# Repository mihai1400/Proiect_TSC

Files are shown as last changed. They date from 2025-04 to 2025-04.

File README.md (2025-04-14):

# Arhitectura Sistemului

## 1. Arhitectura Generală
Sistemul este construit în jurul **ESP32-C6-WROOM-1-N8** (microcontroler Wi-Fi 6 + Bluetooth 5 cu RISC-V) și include:

- **Alimentare & Baterie** (LDO, încărcător Li-Po, monitorizare nivel baterie)
- **Memorie** (Flash extern NOR 64MB, slot SD)
- **Senzori** (BME688 - temperatură/umiditate/presiune/VOC)
- **Afișaj** (E-Paper SPI)
- **Periferice** (RTC DS3231, butoane, LED-uri, USB-C)

## 2. Module & Interfețe cu ESP32-C6

### 2.1. Alimentare & Baterie
| Componentă | Interfață cu ESP32-C6 | Detalii |
|---|---|---|
| LDO (XC6220A331MR-G) | Nu (alimentare 3.3V) | Reglează 3.3V pentru întreg sistemul |
| Încărcător Baterie (MCP73831)  | GPIO4 (STAT) | Semnalizează starea încărcării (LED) |
| Monitor Baterie (MAX17048) | I2C (SDA: GPIO8, SCL: GPIO9)| Măsoară nivelul bateriei (%/tensiune) |

**Calcul consum:**
- ESP32-C6 (~80 mA în mod activ, ~5 µA în sleep)
- BME688 (~2.5 mA când active)
- E-Paper (~100 mA la refresh)
- **Total estimat:** ~200 mA (utilizare normală), sub 1 mA în sleep cu RTC activ

### 2.2. Memorie & Stocare
| Componentă | Interfață cu ESP32-C6 | Detalii |
|---|---|---|
| Flash NOR (W25Q512JVEIQ) | SPI0 (CS: GPIO12, CLK: GPIO14, MOSI: GPIO13, MISO: GPIO11) | Stochează firmware/date |
| Slot SD (J4) | SPI1 (CS: GPIO5, CLK: GPIO6, MOSI: GPIO7, MISO: GPIO10) | Stocare fișiere (FAT32) |

### 2.3. Senzori
| Componentă | Interfață cu ESP32-C6 | Detalii |
|---|---|---|
| BME688 | I2C (SDA: GPIO8, SCL: GPIO9)| Senzor ambiental (temperatură, umiditate, presiune, VOC) |
| RTC (DS3231SN) | I2C (SDA: GPIO8, SCL: GPIO9)| Ceas precis (±2 ppm) cu alarmă |

**Comunicație:**
- BME688 folosește I2C la 400 kHz (adresă `0x76`)
- DS3231 folosește I2C la 100 kHz (adresă `0x68`)

### 2.4. Afișaj E-Paper
| Componentă | Interfață cu ESP32-C6 | Detalii |
|---|---|---|
| Driver E-Paper  | SPI2 (CS: GPIO15, DC: GPIO16, RST: GPIO17, BUSY: GPIO18) | SPI dedicat pentru afișaj |

**Specificații:**
- Rezoluție: 800x600 (4.2" monocrom)
- Consum: ~100 mA la refresh, 0 mA în stare statică

### 2.5. Periferice & I/O
| Componentă | Interfață cu ESP32-C6 | Detalii |
|---|---|---|
| Buton BOOT | GPIO0 | Resetare în mod flash |
| Buton CHANGE | GPIO1 | Schimbă afișajul |
| LED-uri (D1-D12) | GPIO2, GPIO3 | Indicatori vizuali |
| USB-C (J1) | GPIO20 (D+), GPIO21 (D-) | Comunicație serială (CDC) |

## 3. Alocarea Pinilor ESP32-C6
| Pin ESP32-C6 | Funcție | Componentă |
|---|---|---|
| GPIO0 | BOOT | Buton BOOT |
| GPIO1 | INPUT | Buton CHANGE |
| GPIO2-3 | OUTPUT | LED-uri |
| GPIO4 | INPUT | MCP73831 (STAT) |
| GPIO5 | CS | Slot SD |
| GPIO6-7 | SCK/MOSI | Slot SD |
| GPIO8-9 | SDA/SCL | BME688 + DS3231 (I2C) |
| GPIO10 | MISO | Slot SD |
| GPIO11 | MISO | Flash NOR |
| GPIO12 | CS | Flash NOR |
| GPIO13-14 | MOSI/SCK | Flash NOR |
| GPIO15-18 | SPI EPD | Afișaj E-Paper |
| GPIO20-21 | USB D+/D- | USB-C |

## 4. Optimizare Consum Energie
- **Sleep Mode:** ESP32-C6 intră în Deep Sleep cu RTC activ (~5 µA), trezit de DS3231 (alarmă) sau butoane
- **E-Paper:** Folosește energie doar la refresh
- **Senzori:** BME688 este pornit periodic (e.g., la 1 minut)

## 5. Diagramă
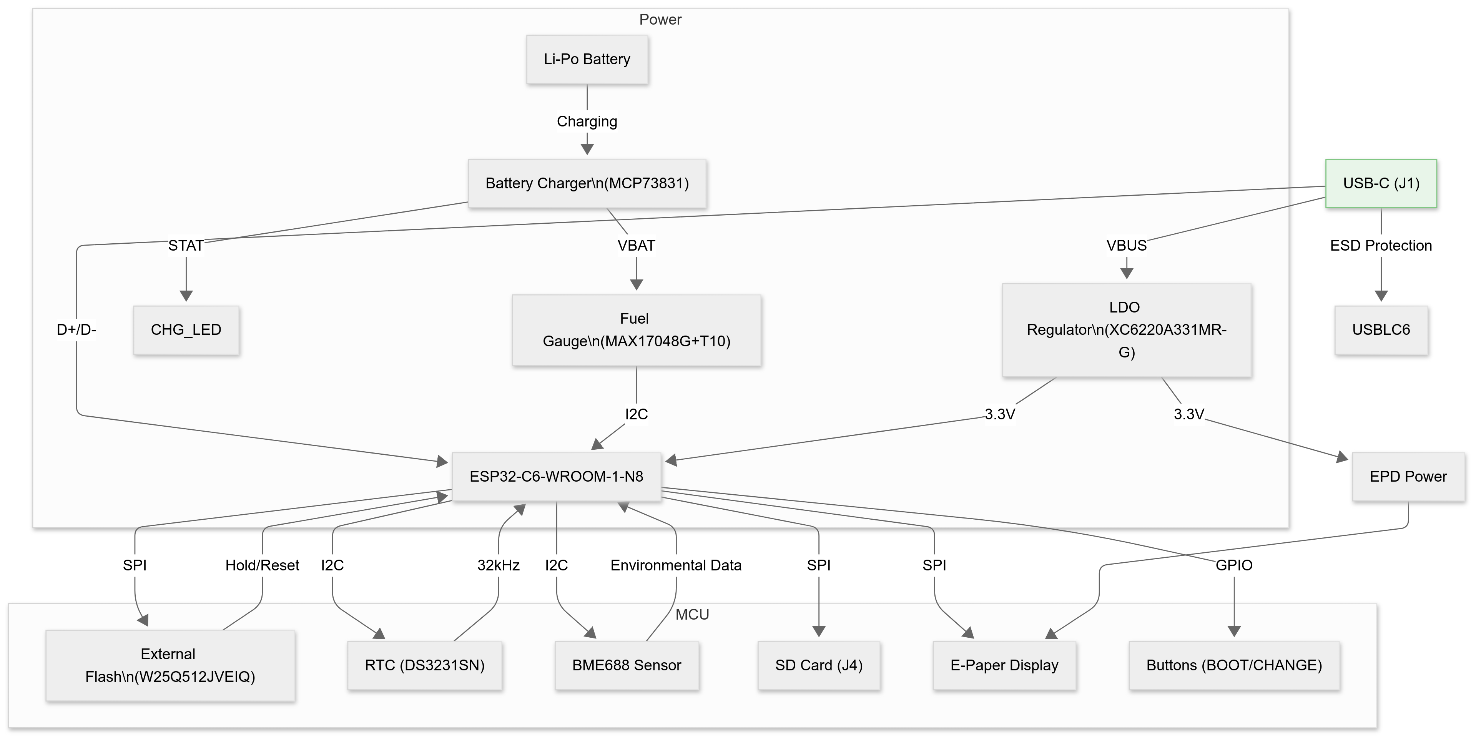
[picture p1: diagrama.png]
Architecture Diagram


## 6. BOM

| Device Module | Amount | Datasheet | Shop |
| --- | --- | ---| ---|
| 112A-TAAR-R03_ATTEND | 1 | https://www.attend.com.tw/en/product.php?act=view&id=253 | https://www.digikey.com/en/products/detail/attend-technology/112A-TAAR-R03/17633923 |
| BD5229G-TR | 1 | https://www.digikey.ph/en/products/detail/rohm-semiconductor/BD5229G-TR/658502 | https://www.digikey.ph/en/products/detail/rohm-semiconductor/BD5229G-TR/658502 |
| BUTTON_COSYOMV1 | 3 | https://components101.com/switches/push-button | https://uk.farnell.com/wurth-elektronik/430182043816/switch-160gf-6x6mm-smd-4-3mm-act/dp/2065105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 |
| CPH3225A | 1 | https://www.digikey.com/en/products/detail/seiko-instruments/CPH3225A/8692444 | https://www.digikey.com/en/products/detail/seiko-instruments/CPH3225A/8692444 |
| DS3231SN | 1 | https://www.digikey.com/en/products/detail/analog-devices-inc-maxim-integrated/DS3231SN/1197576 | https://www.digikey.com/en/products/detail/analog-devices-inc-maxim-integrated/DS3231SN/1197576 |
| BME680 | 1 | https://www.sparkfun.com/sparkfun-environmental-sensor-breakout-bme680-qwiic.html | https://www.sparkfun.com/sparkfun-environmental-sensor-breakout-bme680-qwiic.html |
| MCP73831 | 1 | https://www.microchip.com/en-us/product/mcp73831 | https://www.microchipdirect.com/product/MCP73831T-2ADI/OT |
| C6-WROOM-1-N8 | 1 | https://www.espressif.com/sites/default/files/documentation/esp32-c6-wroom-1_wroom-1u_datasheet_en.pdf | https://www.adafruit.com/product/5671 |
| FH34SRJ-24S-0.5SH_99_ | 1 | https://www.hirose.com/product/p/CL0580-1255-6-99 | https://www.hirose.com/product/p/CL0580-1255-6-99 |
| MAX17048G+T10 | 1 | https://eu.mouser.com/ProductDetail/Analog-Devices-Maxim-Integrated/MAX17048G+T10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 | https://eu.mouser.com/ProductDetail/Analog-Devices-Maxim-Integrated/MAX17048G+T10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 |
| MBR0530 | 3 | https://www.digikey.com/en/products/detail/onsemi/MBR0530/1048783 | https://www.digikey.com/en/products/detail/onsemi/MBR0530/1048783 |
| PGB1010603MR | 6 | https://www.digikey.com/en/products/detail/littelfuse-inc/PGB1010603MR/715755 | https://www.digikey.com/en/products/detail/littelfuse-inc/PGB1010603MR/715755 |
| SAMACSYS_PARTS_USB4110-GF-A | 1 | https://www.digikey.ro/en/products/detail/gct/USB4110-GF-A/10384547 | https://www.digikey.ro/en/products/detail/gct/USB4110-GF-A/10384547 |
| SI1308EDL-T1-GE3 | 1 | https://www.digikey.com/en/products/detail/vishay-siliconix/SI1308EDL-T1-GE3/4876435 | https://www.digikey.com/en/products/detail/vishay-siliconix/SI1308EDL-T1-GE3/4876435 |
| SJ | 1 | https://www.digikey.com/en/products/detail/cui-devices/SJ1-3514N/738685 | https://www.digikey.com/en/products/detail/cui-devices/SJ1-3514N/738685 |
| USBLC6-2SC6Y | 1 | https://www.digikey.com/en/products/detail/stmicroelectronics/USBLC6-2SC6Y/2819177 | https://www.digikey.com/en/products/detail/stmicroelectronics/USBLC6-2SC6Y/2819177 |
| W25Q512JVEIQ | 1 | https://www.digikey.com/en/products/detail/winbond-electronics/W25Q512JVEIQ/10244706 | https://www.digikey.com/en/products/detail/winbond-electronics/W25Q512JVEIQ/10244706 |
| XC6220A331MR-G | 1 | https://www.digikey.com/en/products/detail/torex-semiconductor-ltd/XC6220B331MR-G/2138177 | https://www.digikey.com/en/products/detail/torex-semiconductor-ltd/XC6220B331MR-G/2138177 |
| SD0805S020S1R0 | 2 | https://www.digikey.com/en/products/detail/kyocera-avx/SD0805S020S1R0/3749517 | https://www.digikey.com/en/products/detail/kyocera-avx/SD0805S020S1R0/3749517 |
| LTSPICE_C 100nF | 8 | https://www.digikey.com/en/products/detail/nextgen-components/0402B104K500HI/22601924 | https://www.digikey.com/en/products/detail/nextgen-components/0402B104K500HI/22601924 |
| LTSPICE_C 10nF | 1 | https://www.amazon.com/ALLECIN-Electrolytic-Capacitor-0-2x0-43in-Capacitors/dp/B0CMQC587X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 | https://www.amazon.com/ALLECIN-Electrolytic-Capacitor-0-2x0-43in-Capacitors/dp/B0CMQC587X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 |
| LTSPICE_C 4.7uF | 6 | https://www.amazon.com/ALLECIN-Electrolytic-Capacitor-0-2x0-43in-Capacitors/dp/B0CMQC587X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 | https://www.amazon.com/ALLECIN-Electrolytic-Capacitor-0-2x0-43in-Capacitors/dp/B0CMQC587X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 |
| LTSPICE_C 1uF | 10 | https://www.amazon.com/ALLECIN-Electrolytic-Capacitor-0-2x0-43in-Capacitors/dp/B0CMQC587X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 | https://www.amazon.com/ALLECIN-Electrolytic-Capacitor-0-2x0-43in-Capacitors/dp/B0CMQC587X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 |
| LTSPICE_C 0.1uF | 1 | https://www.digikey.com/en/products/detail/samsung-electro-mechanics/CL10E104KC8VPNC/20498486 | https://www.digikey.com/en/products/detail/samsung-electro-mechanics/CL10E104KC8VPNC/20498486 |
| ADAFRUIT_LED | 1 | https://www.adafruit.com/product/4684 | https://www.adafruit.com/product/4684 |
| ESP32_VARISTOR | 1 | https://uk.rs-online.com/web/p/varistors/9012743 | https://uk.rs-online.com/web/p/varistors/9012743 |
| CT3528 (RCL_CPOL-EU) 100uF | 1 | https://www.datasheetarchive.com/?q=ct3528 |  |
| DMG2305UX-7 20V/4.2A/52mO/1.4W | 2 | https://www.digikey.com/en/products/detail/diodes-incorporated/DMG2305UX-7/4340667 | https://www.digikey.com/en/products/detail/diodes-incorporated/DMG2305UX-7/4340667 |
| IND-4828-WE-TPC-WRE | 1 | https://www.axel-gl.com/en/asone/d/64-0172-48/ | https://www.axel-gl.com/en/asone/d/64-0172-48/ |
| JS-1MM(QWIIC_CONNECTOR) | 1 | https://www.sparkfun.com/qwiic-jst-connector-smd-4-pin-horizontal.html | https://www.sparkfun.com/qwiic-jst-connector-smd-4-pin-horizontal.html |
| LTSPICE_R 5k1 | 2 |  | https://www.amazon.com/BOJACK-Values-Resistor-Resistors-Assortment/dp/B08FD1XVL6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 |
| LTSPICE_R 100k | 1 |  | https://www.amazon.com/BOJACK-Values-Resistor-Resistors-Assortment/dp/B08FD1XVL6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 |
| LTSPICE_R 2.2 | 1 |  | https://www.amazon.com/BOJACK-Values-Resistor-Resistors-Assortment/dp/B08FD1XVL6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 |
| LTSPICE_R 10k | 16 |  | https://www.amazon.com/BOJACK-Values-Resistor-Resistors-Assortment/dp/B08FD1XVL6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 |
| LTSPICE_R 0.47 | 1 |  | https://www.amazon.com/BOJACK-Values-Resistor-Resistors-Assortment/dp/B08FD1XVL6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 |
| LTSPICE_R 2k | 1 |  | https://www.amazon.com/BOJACK-Values-Resistor-Resistors-Assortment/dp/B08FD1XVL6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 |
| LTSPICE_R 200 | 1 |  | https://www.amazon.com/BOJACK-Values-Resistor-Resistors-Assortment/dp/B08FD1XVL6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 |
| LTSPICE_R 15 | 1 |  | https://www.amazon.com/BOJACK-Values-Resistor-Resistors-Assortment/dp/B08FD1XVL6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 |
| Test Pad TP20R | 17 | https://us.misumi-ec.com/vona2/detail/221005496391/?HissuCode=TP20R-24 | https://us.misumi-ec.com/vona2/detail/221005496391/?HissuCode=TP20R-24 |

## 7. Concluzii
- ESP32-C6 este nucleul sistemului, cu 3 interfețe SPI (Flash, SD, E-Paper) și I2C partajat (BME688 + DS3231)
- BME688 oferă date ambientale, iar DS3231 menține timpul precis
- Consum redus în sleep (~5 µA) permite funcționare pe baterie >1 lună

Probleme : 
 - Nu pot genera fiserul .step (se blocheaza Fusion-ul cand incerc)

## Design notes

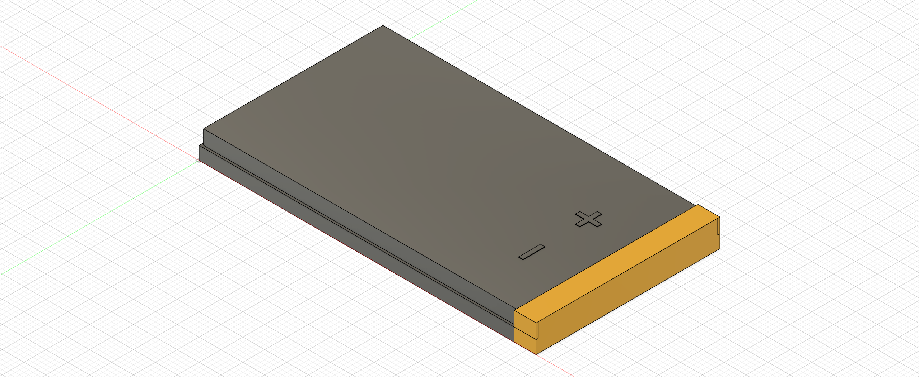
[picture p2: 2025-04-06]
Images/Baterie v1.png

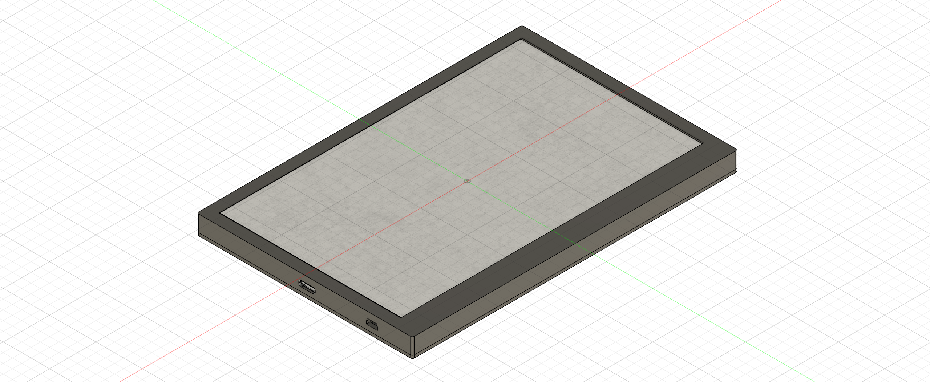
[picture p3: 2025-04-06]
Images/EBOOKREADER.png

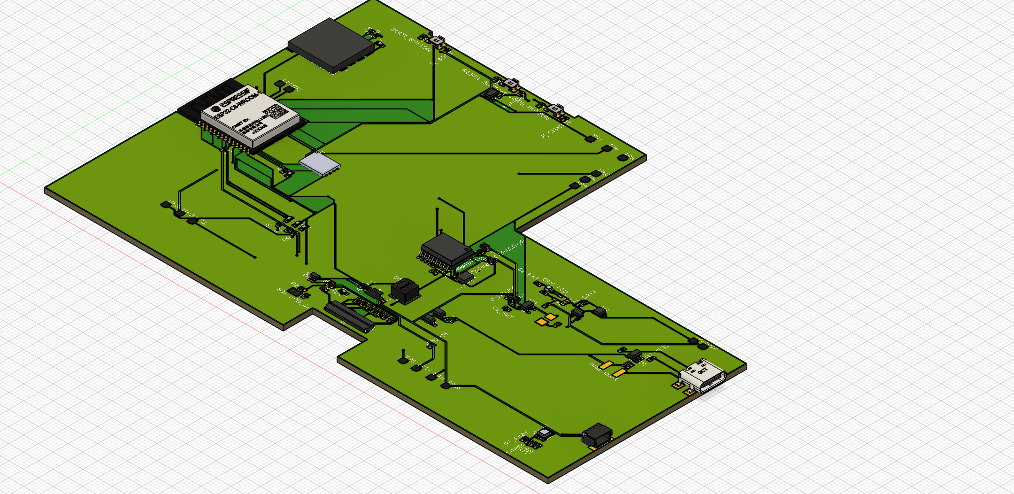
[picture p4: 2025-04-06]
Images/ProiectTSC v4.png

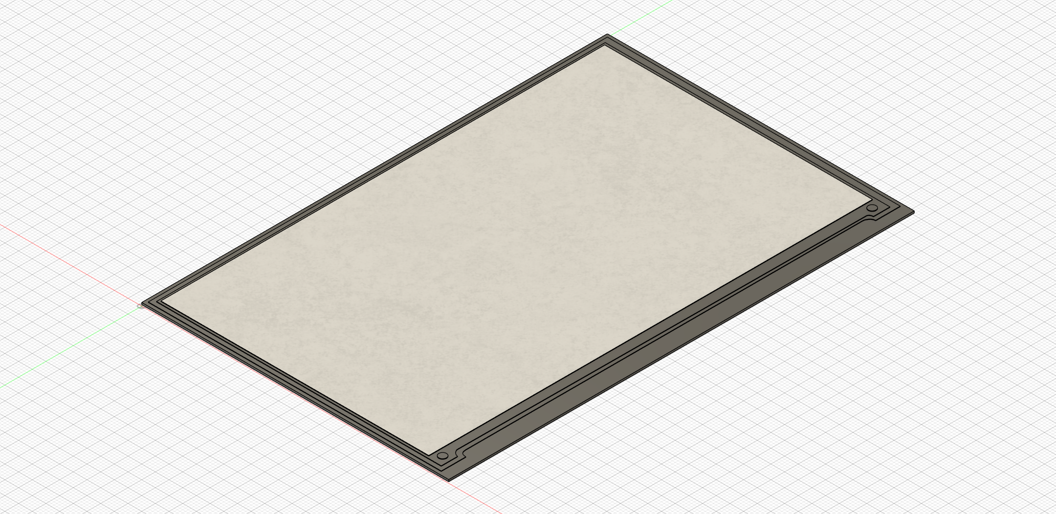
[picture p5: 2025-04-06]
Images/Display v4.png

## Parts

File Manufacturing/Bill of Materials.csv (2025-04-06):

BOOT_BUTTON | 36.65 | 112.67 | 180.00 | BUTTON_CUSYOMV1 | MYBUTTON
C1 | 170.35 | 11.74 | 90.00 | 100nf | ESP32_WROVER_EAGLE-LTSPICE_C0402
C10 | 72.51 | 112.21 | 270.00 | 100nF | ESP32_WROVER_EAGLE-LTSPICE_C0402
C10_SUPERCAP | 110.76 | 48.41 | 270.00 | CPH3225A | CAPCP3225X100N
C1_BAT | 126.31 | 46.88 | 0.00 | 4.7uF | ESP32_WROVER_EAGLE-LTSPICE_C0402
C1_BAT1 | 139.51 | 50.62 | 90.00 | 4.7uF | ESP32_WROVER_EAGLE-LTSPICE_C0402
C1_BAT2 | 137.87 | 61.45 | 90.00 | 4.7uF | ESP32_WROVER_EAGLE-LTSPICE_C0402
C2 | 171.77 | 11.84 | 90.00 | 100nf | ESP32_WROVER_EAGLE-LTSPICE_C0402
C2_BAT | 124.25 | 59.41 | 0.00 | 4.7uF | ESP32_WROVER_EAGLE-LTSPICE_C0402
C3 | 136.08 | 50.48 | 270.00 | 100uF TANT | RCL_CT3528
C4 | 120.74 | 34.42 | 90.00 | 4.7uF/25V | ESP32_WROVER_EAGLE-LTSPICE_C0402
C4_USB | 163.22 | 50.13 | 0.00 | 100nF | ESP32_WROVER_EAGLE-LTSPICE_C0402
C5 | 57.57 | 112.21 | 270.00 | 1uF | ESP32_WROVER_EAGLE-LTSPICE_C0402
C5_USB | 163.21 | 51.43 | 0.00 | 4.7uF | ESP32_WROVER_EAGLE-LTSPICE_C0402
C6 | 32.61 | 112.21 | 270.00 | 100nF | ESP32_WROVER_EAGLE-LTSPICE_C0402
C7 | 102.62 | 28.14 | 0.00 | 10uF | ESP32_WROVER_EAGLE-LTSPICE_C0402
C8 | 103.27 | 45.19 | 0.00 | 100nF | ESP32_WROVER_EAGLE-LTSPICE_C0402
C9 | 22.45 | 104.72 | 90.00 | 100nF | ESP32_WROVER_EAGLE-LTSPICE_C0402
CHANGE_BUTTON | 76.61 | 112.73 | 180.00 | BUTTON_CUSYOMV1 | MYBUTTON
C_DELAY | 123.20 | 50.60 | 90.00 | 100nF | ESP32_WROVER_EAGLE-LTSPICE_C0402
D1 | 162.18 | 54.30 | 0.00 | USBLC6-2SC6Y | SOT95P280X145-6N
D10 | 68.35 | 36.39 | 90.00 | PGB1010603MR | DIOC1608X36N
D11 | 27.59 | 102.84 | 0.00 | PGB1010603MR | DIOC1608X36N
D12 | 93.99 | 24.23 | 0.00 | PGB1010603MR | DIOC1608X36N
D2 | 125.60 | 50.52 | 90.00 | ESP32_WROVER_AVX---SD0805S020S1R0_AVX_SD0805S020S1R0_0_0AVX_SD0805S020S1R0_0_0 | ESP32_WROVER_AVX---SD0805S020S1R0_AVX_SD0805S020S1R0_0
D3 | 116.94 | 33.52 | 180.00 | MBR0530 | SOD3716X135N
D4 | 116.96 | 29.97 | 0.00 | MBR0530 | SOD3716X135N
D5 | 103.34 | 36.94 | 180.00 | MBR0530 | SOD3716X135N
D6 | 50.32 | 49.59 | 90.00 | PGB1010603MR | DIOC1608X36N
D7 | 104.87 | 60.98 | 0.00 | ESP32_WROVER_AVX---SD0805S020S1R0_AVX_SD0805S020S1R0_0_0AVX_SD0805S020S1R0_0_0 | ESP32_WROVER_AVX---SD0805S020S1R0_AVX_SD0805S020S1R0_0
D8 | 63.33 | 36.29 | 90.00 | PGB1010603MR | DIOC1608X36N
D9 | 66.14 | 36.39 | 90.00 | PGB1010603MR | DIOC1608X36N
EPC_C6 | 110.16 | 24.09 | 90.00 | 1uF/50V | ESP32_WROVER_EAGLE-LTSPICE_C0402
EPC_C8 | 106.34 | 24.09 | 90.00 | 1uF/50V | ESP32_WROVER_EAGLE-LTSPICE_C0402
EPD_C1 | 88.53 | 16.59 | 90.00 | 1uF/50V | ESP32_WROVER_EAGLE-LTSPICE_C0402
EPD_C10 | 102.52 | 24.09 | 90.00 | 1uF/50V | ESP32_WROVER_EAGLE-LTSPICE_C0402
EPD_C11 | 100.61 | 24.09 | 90.00 | 1uF/50V | ESP32_WROVER_EAGLE-LTSPICE_C0402
EPD_C12 | 98.70 | 24.09 | 90.00 | 1uF/50V | ESP32_WROVER_EAGLE-LTSPICE_C0402
EPD_C2 | 89.69 | 21.78 | 0.00 | 1uF/50V | ESP32_WROVER_EAGLE-LTSPICE_C0402
EPD_C5 | 124.54 | 23.39 | 90.00 | 0.1uF/50V | ESP32_WROVER_EAGLE-LTSPICE_C0402
EPD_C7 | 108.15 | 24.09 | 90.00 | 1uF/50V | ESP32_WROVER_EAGLE-LTSPICE_C0402
EPD_C9 | 104.53 | 24.09 | 90.00 | 1uF/50V | ESP32_WROVER_EAGLE-LTSPICE_C0402
GHC_LED | 127.92 | 59.53 | 90.00 |  | ADAFRUIT_CHIP-LED0603
IC1 | 129.58 | 50.48 | 0.00 | BD5229G-TR | SOT95P280X125-5N
IC4 | 61.69 | 106.50 | 0.00 | XC6220A331MR-G | SOT95P280X120-5N
J1 | 102.58 | 17.78 | 0.00 | FH34SRJ-24S-0.5SH_99_ | FH34SRJ24S05SH99
J2 | 179.27 | 58.60 | 90.00 | SAMACSYS_PARTS_USB4110-GF-A | SAMACSYS_PARTS_USB4110GFA
J3 | 179.74 | 23.56 | 90.00 | QWIIC_RIGHT_ANGLE | JST04_1MM_RA
J4 | 21.00 | 93.15 | 270.00 | 112A-TAAR-R03_ATTEND | 112ATAARR03ATTEND
L1 | 105.23 | 33.55 | 0.00 | 744043680IND_4828-WE-TPC_WRE | IND_4828-WE-TPC_WRE
MCP73831 | 132.99 | 58.63 | 90.00 | ESP32_WROVER_SPARKFUN-IC-POWER_MCP73831 | ESP32_WROVER_SPARKFUN-IC-POWER_SOT23-5
PFMF.050.1 | 161.86 | 47.20 | 180.00 | ESP32C6_VARISTORCN1812 | ESP32C6_VARISTOR_CT/CN1812
Q1 | 140.29 | 56.91 | 0.00 | 20V/4.2A/52mΩ/1.4W | ESP32_WROVER_SPARKFUN-DISCRETESEMI_SOT23-3
Q2 | 99.53 | 29.04 | 270.00 | 20V/4.2A/52mΩ/1.4W | ESP32_WROVER_SPARKFUN-DISCRETESEMI_SOT23-3
Q3 | 84.96 | 23.36 | 90.00 | SI1308EDL-T1-GE3 | SOT65P210X110-3N
R1 | 31.93 | 45.77 | 270.00 | 10K | ESP32_WROVER_EAGLE-LTSPICE_R0402
R10 | 24.40 | 104.69 | 90.00 | 10K | ESP32_WROVER_EAGLE-LTSPICE_R0402
R1_BAT | 127.93 | 57.90 | 0.00 | 200 | ESP32_WROVER_EAGLE-LTSPICE_R0402
R1_PINH | 167.34 | 11.74 | 90.00 | 10K | ESP32_WROVER_EAGLE-LTSPICE_R0402
R1_PINH1 | 107.99 | 48.29 | 90.00 | 10K | ESP32_WROVER_EAGLE-LTSPICE_R0402
R1_PWRUSB | 105.28 | 59.16 | 180.00 |  | ESP32_WROVER_EAGLE-LTSPICE_R0402
R2 | 86.10 | 18.23 | 0.00 | 2.2 | ESP32_WROVER_EAGLE-LTSPICE_R0402
R2-PINH | 168.83 | 11.74 | 90.00 | 10K | ESP32_WROVER_EAGLE-LTSPICE_R0402
R2-PINH1 | 108.73 | 58.21 | 270.00 | 10K | ESP32_WROVER_EAGLE-LTSPICE_R0402
R2-USB | 157.78 | 54.29 | 90.00 | 5k1 | ESP32_WROVER_EAGLE-LTSPICE_R0402
R2-USB1 | 165.38 | 56.78 | 90.00 | 5k1 | ESP32_WROVER_EAGLE-LTSPICE_R0402
R2_BAT | 132.01 | 54.65 | 90.00 | 2K | ESP32_WROVER_EAGLE-LTSPICE_R0402
R3 | 88.94 | 24.31 | 90.00 | 0.47 | ESP32_WROVER_EAGLE-LTSPICE_R0402
R4 | 90.42 | 24.32 | 90.00 | 10K | ESP32_WROVER_EAGLE-LTSPICE_R0402
R5 | 95.29 | 29.11 | 270.00 | 10K | ESP32_WROVER_EAGLE-LTSPICE_R0402
R6 | 48.36 | 49.59 | 90.00 | 10K | ESP32_WROVER_EAGLE-LTSPICE_R0402
R7 | 63.37 | 33.09 | 90.00 | 10K | ESP32_WROVER_EAGLE-LTSPICE_R0402
R8 | 66.28 | 33.09 | 90.00 | 10K | ESP32_WROVER_EAGLE-LTSPICE_R0402
R9 | 68.39 | 33.09 | 90.00 | 10K | ESP32_WROVER_EAGLE-LTSPICE_R0402
RESET_BUTTON | 61.65 | 112.72 | 180.00 | BUTTON_CUSYOMV1 | MYBUTTON
R_BOOT | 40.69 | 112.21 | 270.00 | 10K | ESP32_WROVER_EAGLE-LTSPICE_R0402
R_CAPACITOR | 110.43 | 58.27 | 90.00 | 15 | ESP32_WROVER_EAGLE-LTSPICE_R0402
R_CHANGE | 80.69 | 112.21 | 270.00 | 10K | ESP32_WROVER_EAGLE-LTSPICE_R0402
R_CL1 | 97.01 | 29.09 | 90.00 | 10K | ESP32_WROVER_EAGLE-LTSPICE_R0402
R_RESET | 65.75 | 112.21 | 270.00 | 10K | ESP32_WROVER_EAGLE-LTSPICE_R0402
SENSOR2 | 169.62 | 16.39 | 90.00 | ESP32_WROVER_BME680_BME680 | ESP32_WROVER_BME680_PSON80P300X300X100-8N
SJ1 | 85.68 | 15.95 | 0.00 |  | SJ
TP1 | 22.19 | 74.38 | 0.00 | TPTP20R | TP20R
TP10 | 38.29 | 19.76 | 0.00 | TPTP20R | TP20R
TP11 | 47.59 | 19.38 | 0.00 | TPTP20R | TP20R
TP12 | 101.89 | 101.50 | 0.00 | TPTP20R | TP20R
TP13 | 43.19 | 19.52 | 0.00 | TPTP20R | TP20R
TP14 | 170.59 | 68.94 | 0.00 | TPTP20R | TP20R
TP15 | 133.69 | 14.06 | 0.00 | TPTP20R | TP20R
TP16 | 138.59 | 14.08 | 0.00 | TPTP20R | TP20R
TP17 | 128.49 | 14.20 | 0.00 | TPTP20R | TP20R
TP2 | 25.39 | 74.30 | 0.00 | TPTP20R | TP20R
TP3 | 167.29 | 69.02 | 0.00 | TPTP20R | TP20R
TP4 | 101.79 | 97.94 | 0.00 | TPTP20R | TP20R
TP5 | 101.79 | 110.66 | 0.00 | TPTP20R | TP20R
TP6 | 96.39 | 110.68 | 0.00 | TPTP20R | TP20R
TP7 | 90.89 | 110.60 | 0.00 | TPTP20R | TP20R
TP8 | 124.09 | 14.22 | 0.00 | TPTP20R | TP20R
TP9 | 101.89 | 94.34 | 0.00 | TPTP20R | TP20R
U1 | 52.62 | 57.34 | 0.00 | W25Q512JVEIQ | SON127P600X800X80-9N
U2 | 28.74 | 57.95 | 90.00 | ESP32-C6-WROOM-1-N8 | XCVR_ESP32-C6-WROOM-1-N8
U3 | 100.84 | 52.32 | 270.00 | DS3231SN# | SOIC127P1032X265-16N
U4 | 143.14 | 61.46 | 0.00 | MAX17048G+T10 | SON50P200X200X80-9N

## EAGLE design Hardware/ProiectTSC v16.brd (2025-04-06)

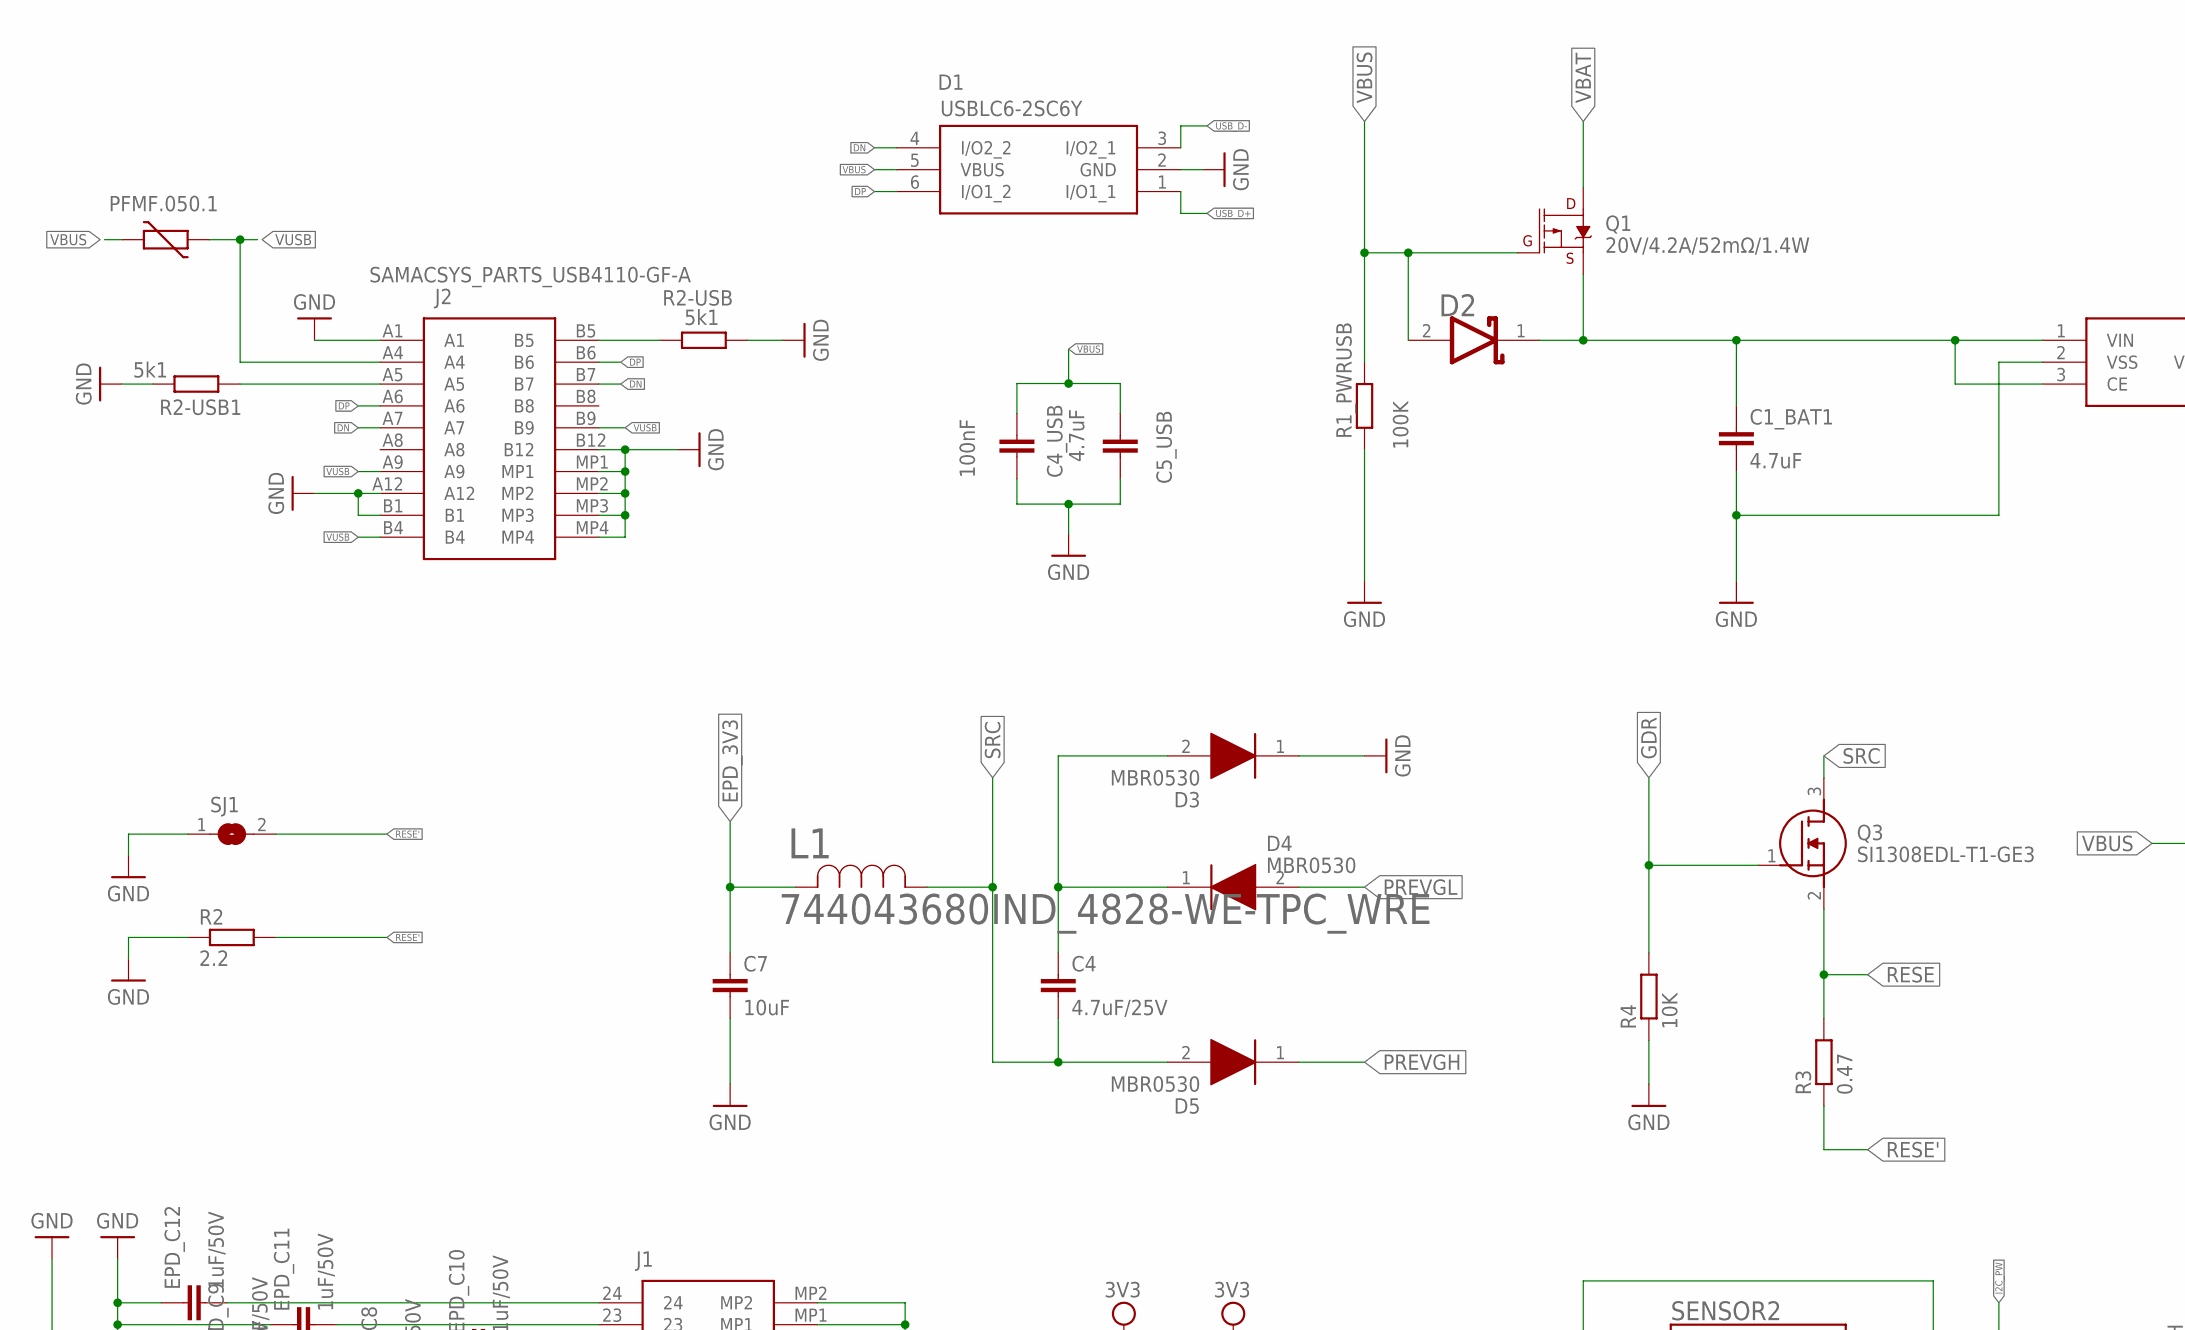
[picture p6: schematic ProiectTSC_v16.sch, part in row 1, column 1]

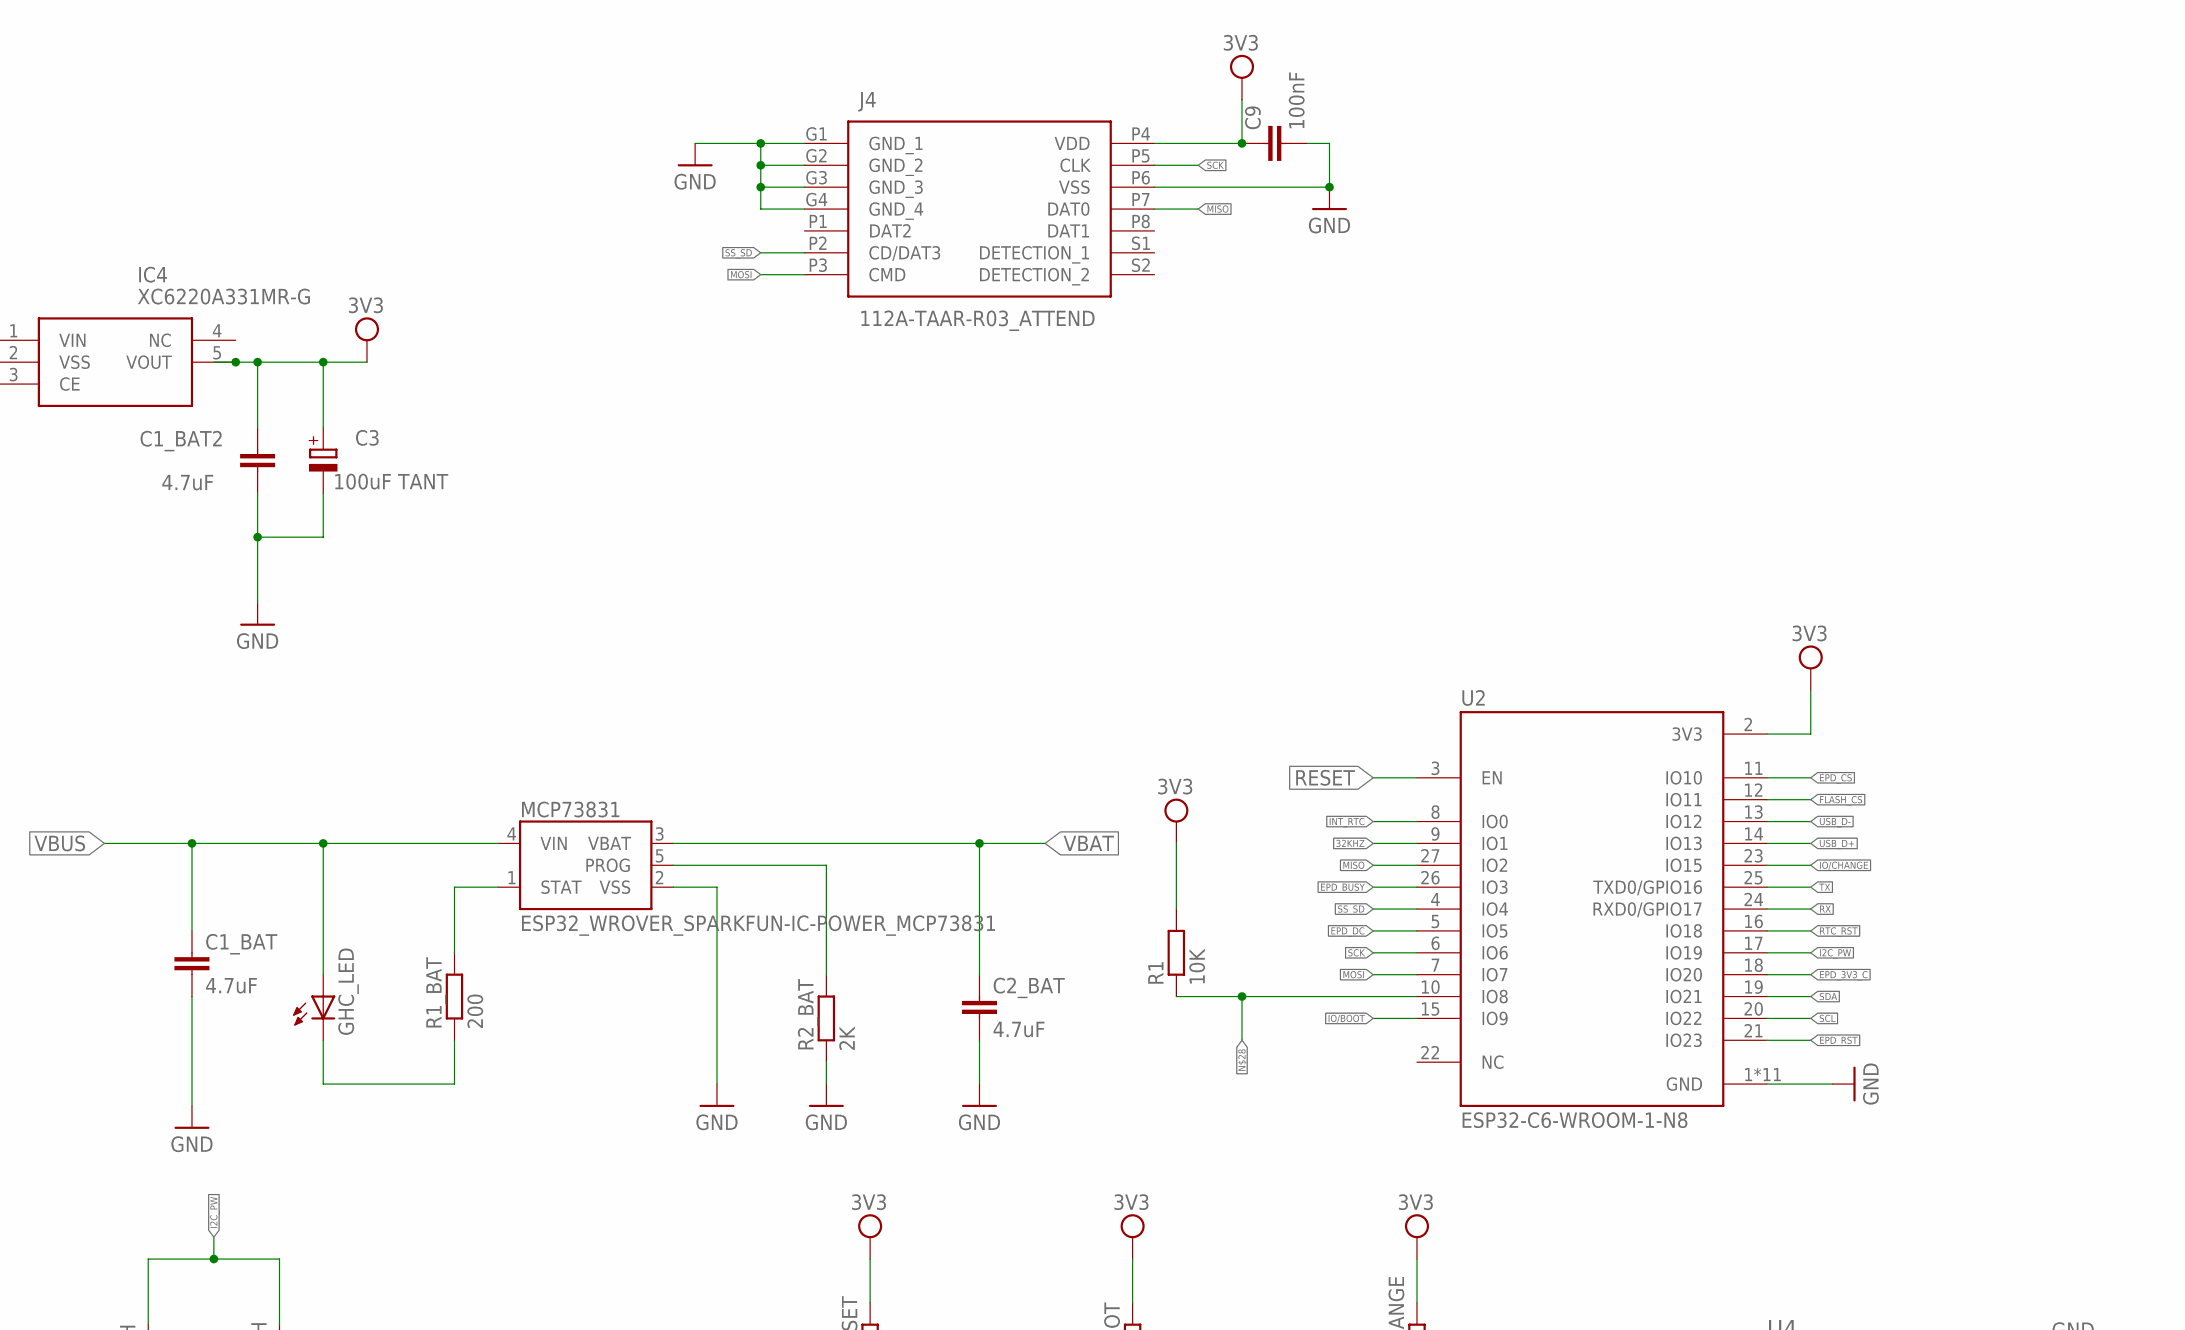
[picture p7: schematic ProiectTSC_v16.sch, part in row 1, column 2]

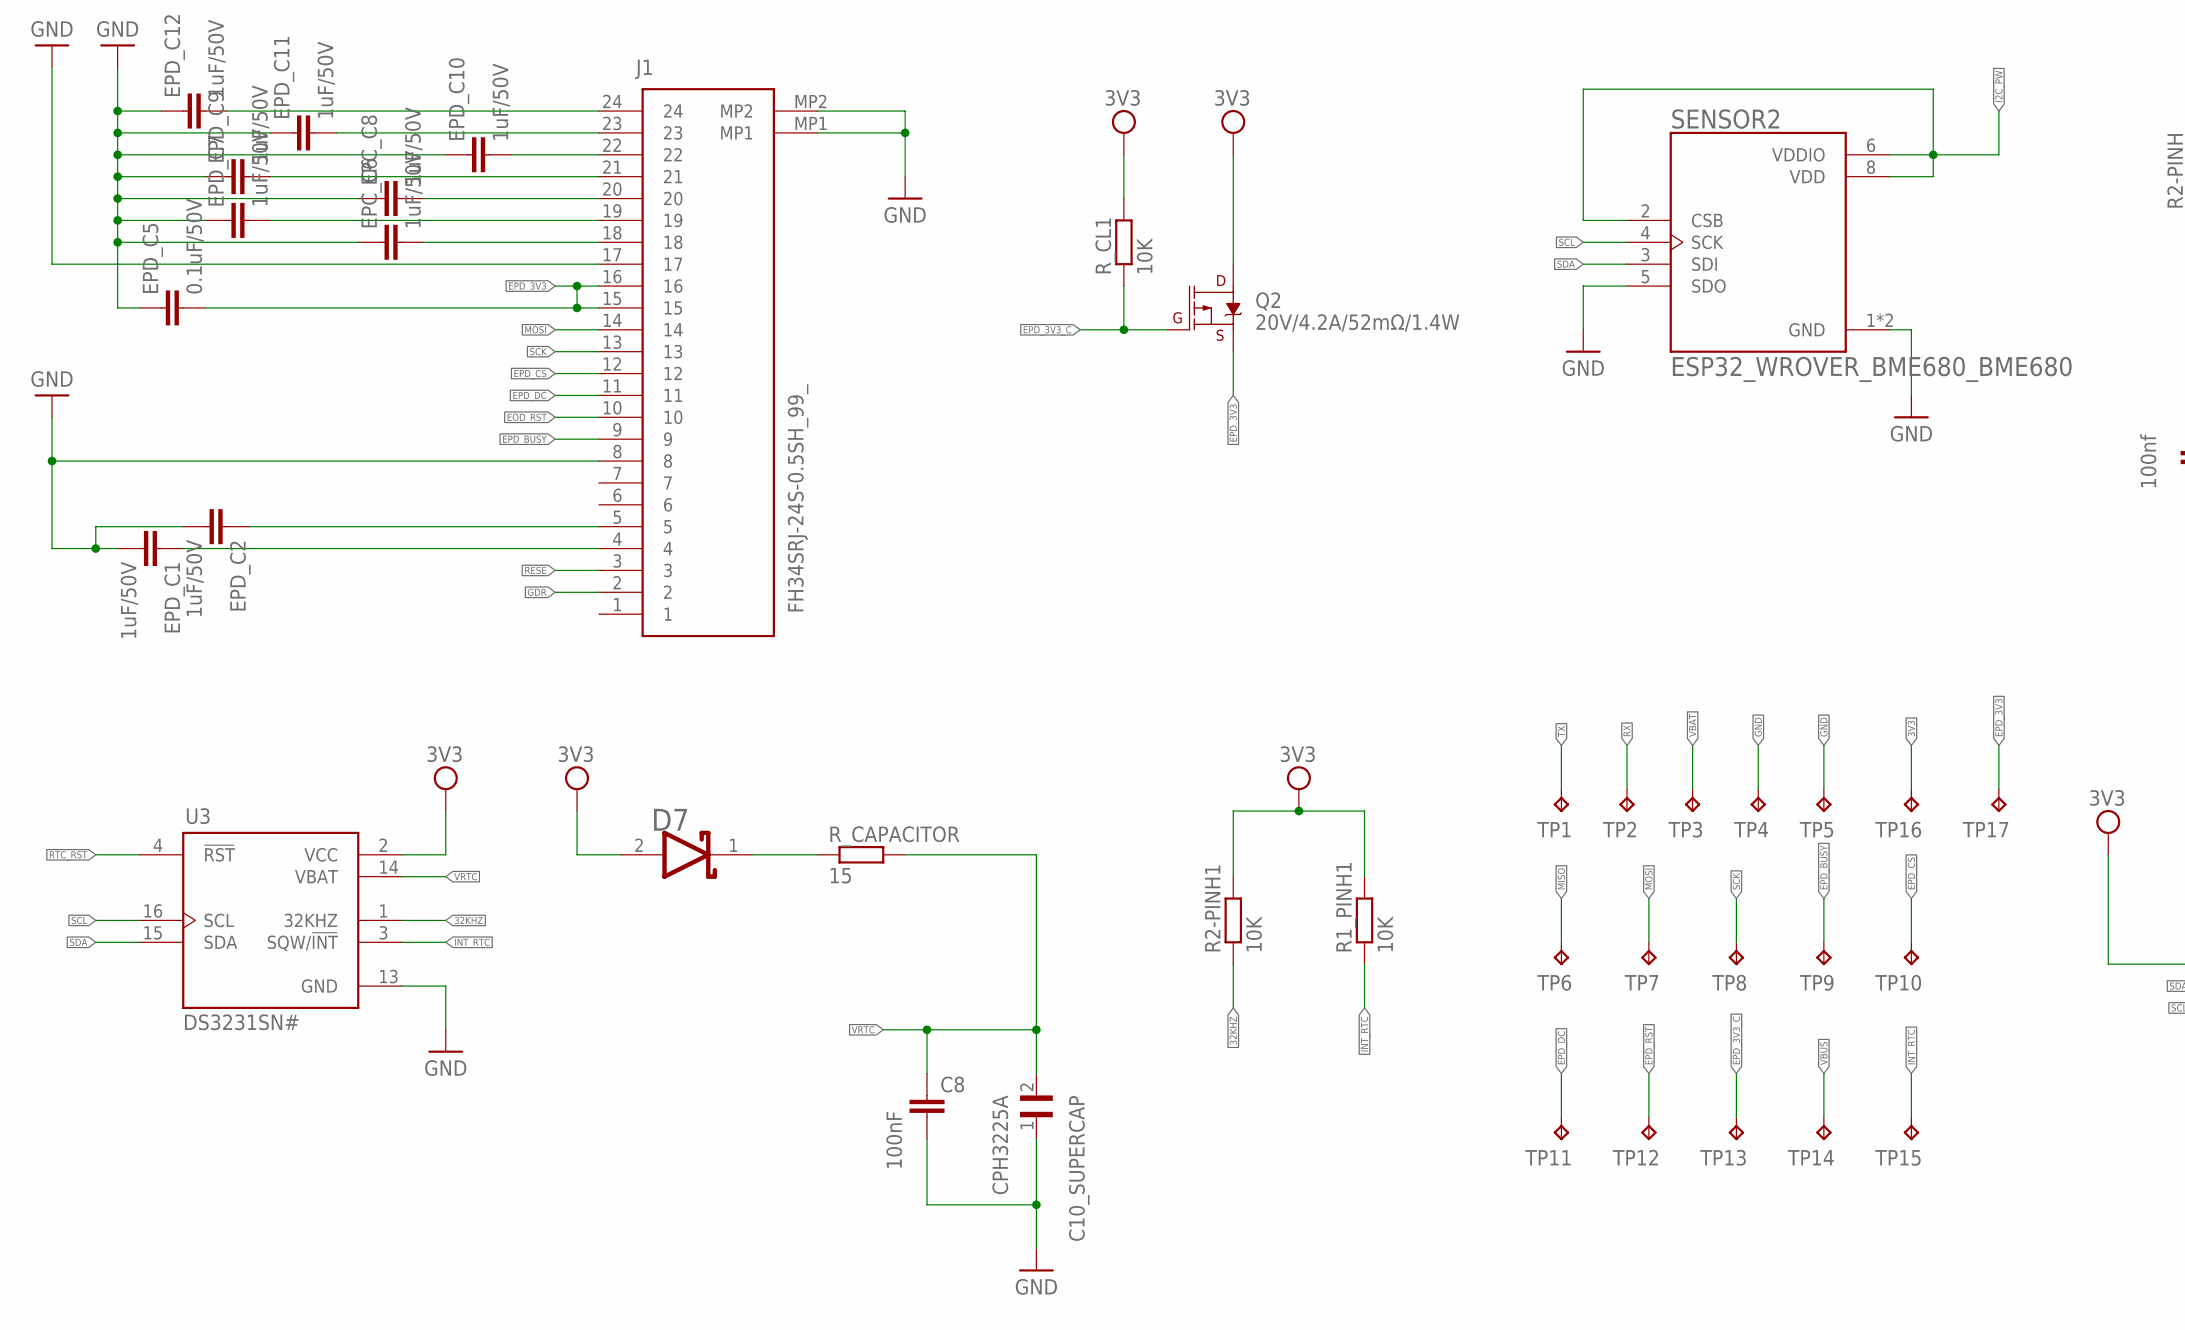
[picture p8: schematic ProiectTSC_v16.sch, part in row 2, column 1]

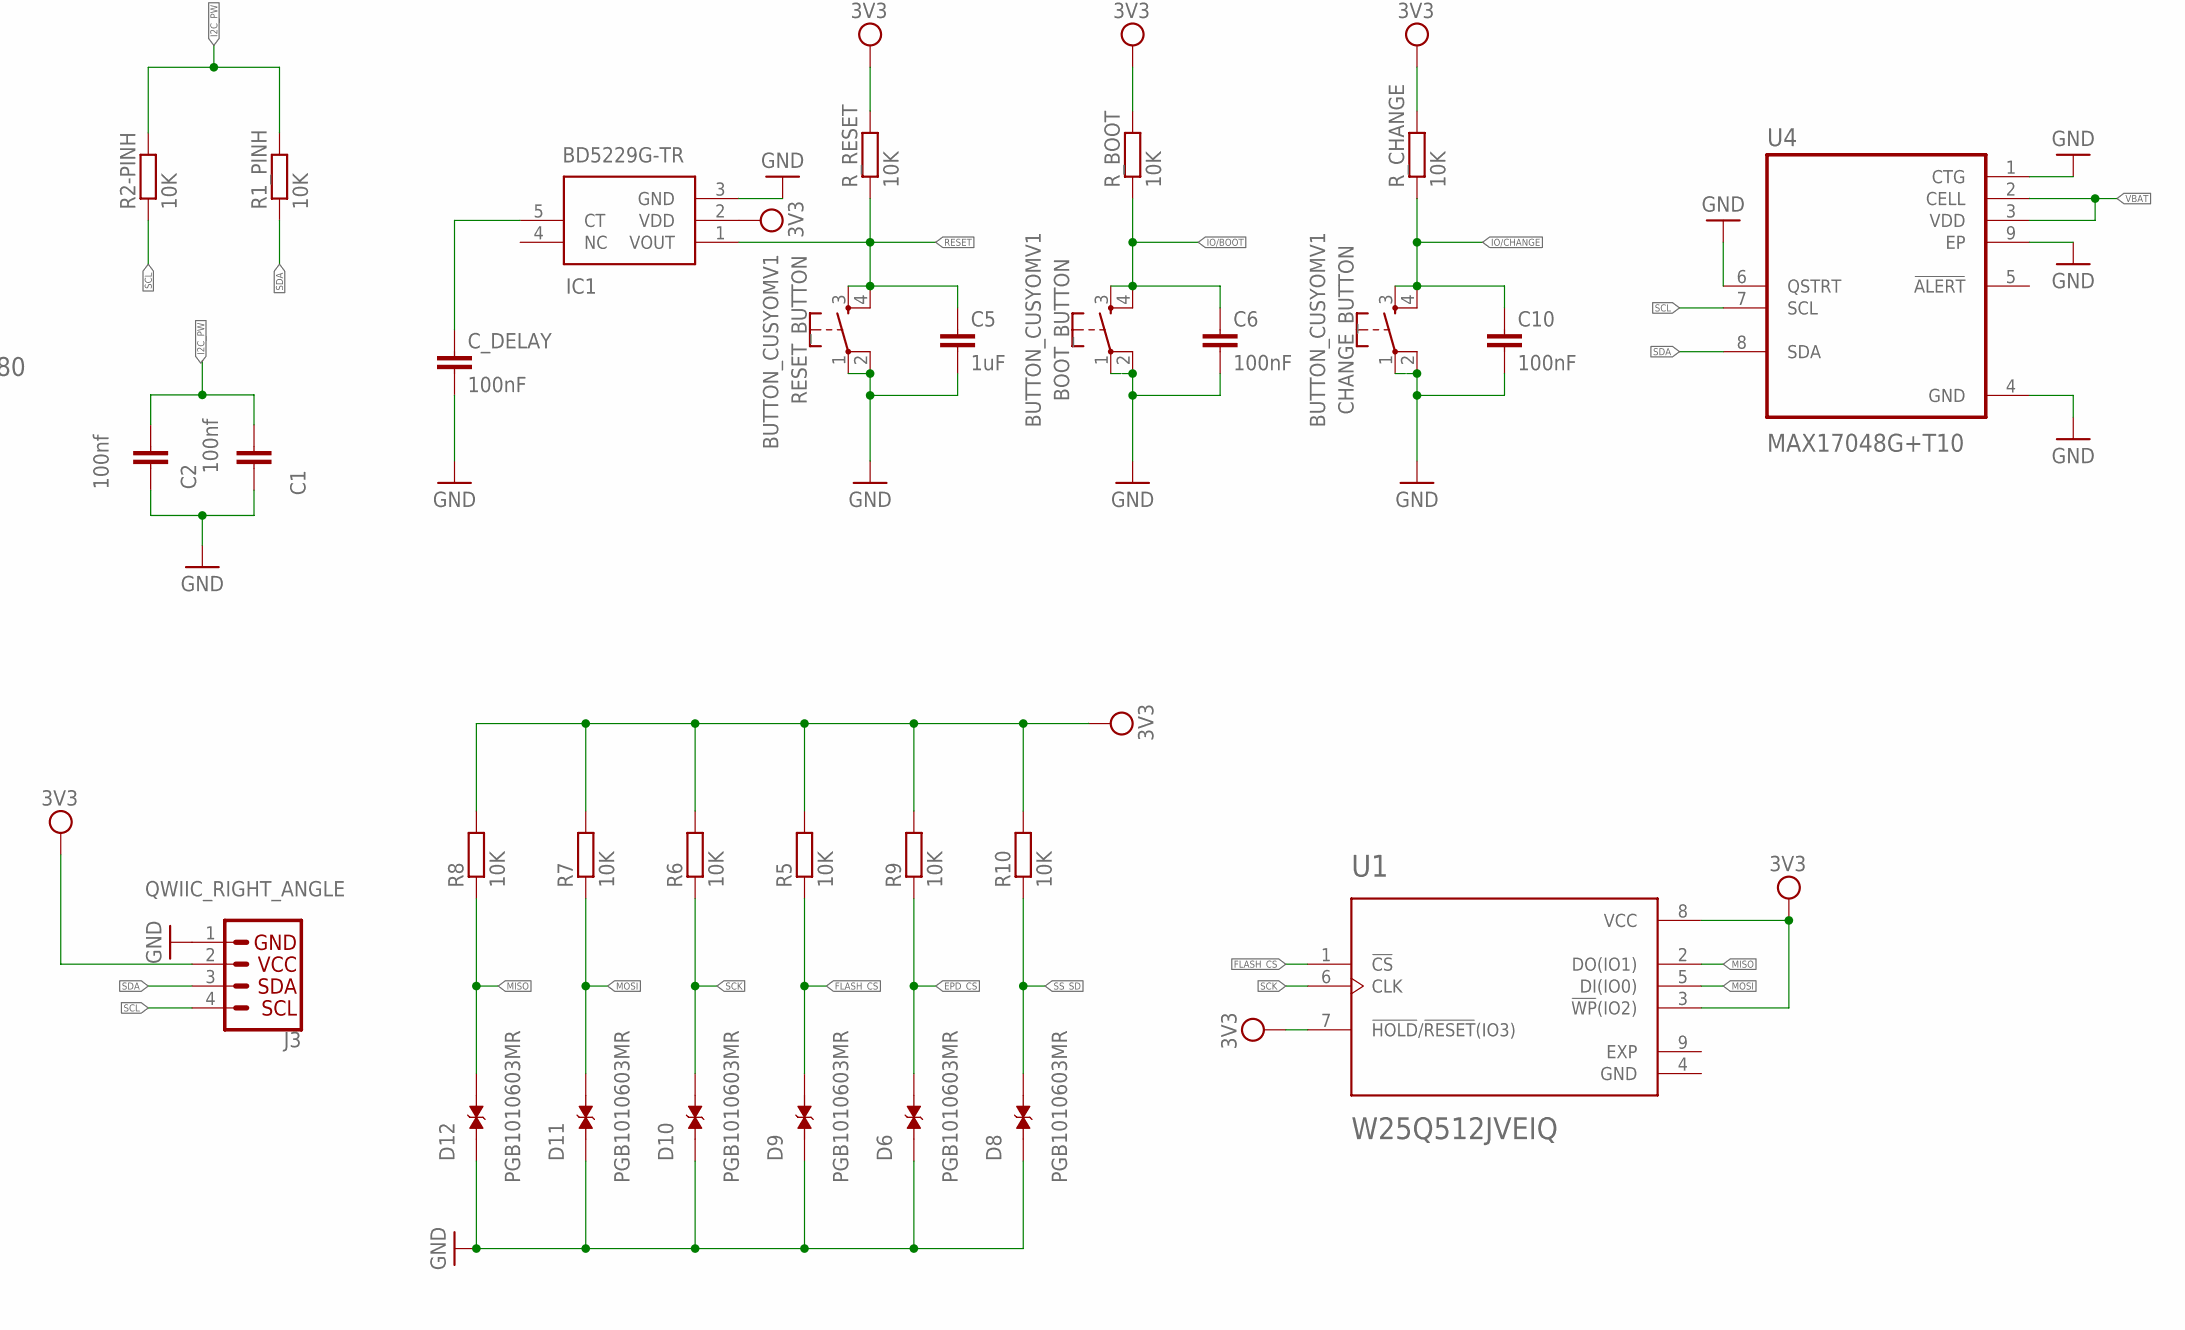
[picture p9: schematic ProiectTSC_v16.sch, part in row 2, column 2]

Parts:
BOOT_BUTTON: BUTTON_CUSYOMV1; MYBUTTON
C1, C2: 100nf; ESP32_WROVER_EAGLE-LTSPICE_C0402
C1_BAT, C1_BAT1, C1_BAT2, C2_BAT, C5_USB: 4.7uF; ESP32_WROVER_EAGLE-LTSPICE_C0402
C3: 100uF TANT; RCL_CT3528
C4: 4.7uF/25V; ESP32_WROVER_EAGLE-LTSPICE_C0402
C4_USB, C6, C8, C9, C10: 100nF; ESP32_WROVER_EAGLE-LTSPICE_C0402
C5: 1uF; ESP32_WROVER_EAGLE-LTSPICE_C0402
C7: 10uF; ESP32_WROVER_EAGLE-LTSPICE_C0402
C10_SUPERCAP: CPH3225A; CAPCP3225X100N
CHANGE_BUTTON: BUTTON_CUSYOMV1; MYBUTTON
C_DELAY: 100nF; ESP32_WROVER_EAGLE-LTSPICE_C0402
D1: USBLC6-2SC6Y; SOT95P280X145-6N
D2, D7: ESP32_WROVER_AVX---SD0805S020S1R0_AVX_SD0805S020S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; ESP32_WROVER_AVX---SD0805S020S1R0_AVX_SD0805S020S1R0_0
D3, D4, D5: MBR0530; SOD3716X135N
D6, D8, D9, D10, D11, D12: PGB1010603MR; DIOC1608X36N
EPC_C6, EPC_C8: 1uF/50V; ESP32_WROVER_EAGLE-LTSPICE_C0402
EPD_C1, EPD_C2, EPD_C7, EPD_C9, EPD_C10, EPD_C11, EPD_C12: 1uF/50V; ESP32_WROVER_EAGLE-LTSPICE_C0402
EPD_C5: 0.1uF/50V; ESP32_WROVER_EAGLE-LTSPICE_C0402
GHC_LED: ADAFRUIT_LEDCHIP-LED0603; ADAFRUIT_CHIP-LED0603
IC1: BD5229G-TR; SOT95P280X125-5N
IC4: XC6220A331MR-G; SOT95P280X120-5N
J1: FH34SRJ-24S-0.5SH_99_; FH34SRJ24S05SH99
J2: SAMACSYS_PARTS_USB4110-GF-A; SAMACSYS_PARTS_USB4110GFA
J3: QWIIC_RIGHT_ANGLE; JST04_1MM_RA
J4: 112A-TAAR-R03_ATTEND; 112ATAARR03ATTEND
L1: 744043680IND_4828-WE-TPC_WRE; IND_4828-WE-TPC_WRE
MCP73831: ESP32_WROVER_SPARKFUN-IC-POWER_MCP73831; ESP32_WROVER_SPARKFUN-IC-POWER_SOT23-5
PFMF.050.1: ESP32C6_VARISTORCN1812; ESP32C6_VARISTOR_CT/CN1812
Q1, Q2: 20V/4.2A/52mΩ/1.4W; ESP32_WROVER_SPARKFUN-DISCRETESEMI_SOT23-3
Q3: SI1308EDL-T1-GE3; SOT65P210X110-3N
R1, R1_PINH, R1_PINH1, R2-PINH, R2-PINH1, R4, R5, R6, R7, R8, R9, R10: 10K; ESP32_WROVER_EAGLE-LTSPICE_R0402
R1_BAT: 200; ESP32_WROVER_EAGLE-LTSPICE_R0402
R1_PWRUSB: ESP32_WROVER_EAGLE-LTSPICE_RR0402; ESP32_WROVER_EAGLE-LTSPICE_R0402
R2: 2.2; ESP32_WROVER_EAGLE-LTSPICE_R0402
R2-USB, R2-USB1: 5k1; ESP32_WROVER_EAGLE-LTSPICE_R0402
R2_BAT: 2K; ESP32_WROVER_EAGLE-LTSPICE_R0402
R3: 0.47; ESP32_WROVER_EAGLE-LTSPICE_R0402
RESET_BUTTON: BUTTON_CUSYOMV1; MYBUTTON
R_BOOT: 10K; ESP32_WROVER_EAGLE-LTSPICE_R0402
R_CAPACITOR: 15; ESP32_WROVER_EAGLE-LTSPICE_R0402
R_CHANGE: 10K; ESP32_WROVER_EAGLE-LTSPICE_R0402
R_CL1: 10K; ESP32_WROVER_EAGLE-LTSPICE_R0402
R_RESET: 10K; ESP32_WROVER_EAGLE-LTSPICE_R0402
SENSOR2: ESP32_WROVER_BME680_BME680; ESP32_WROVER_BME680_PSON80P300X300X100-8N
SJ1: SJ
TP1, TP2, TP3, TP4, TP5, TP6, TP7, TP8, TP9, TP10, TP11, TP12, TP13, TP14, TP15, TP16, TP17: TPTP20R; TP20R
U1: W25Q512JVEIQ; SON127P600X800X80-9N
U2: ESP32-C6-WROOM-1-N8; XCVR_ESP32-C6-WROOM-1-N8
U3: DS3231SN#; SOIC127P1032X265-16N
U4: MAX17048G+T10; SON50P200X200X80-9N

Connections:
3V3: C1_BAT2.1, C3.+, C9.1, D7.2 (ANODE), IC1.2 (VDD), IC4.5 (VOUT), J3.2, J4.P4 (VDD), Q2.3 (D), R1.2, R1_PINH1.2, R2-PINH1.2, R5.2, R6.2, R7.2, R8.2, R9.2, R10.2, R_BOOT.2, R_CHANGE.2, R_CL1.2, R_RESET.2, TP16.TP, U1.3 (!WP!(IO2)), U1.7 (!HOLD!/!RESET!(IO3)), U1.8 (VCC), U2.2 (3V3), U3.2 (VCC)
32KHZ: R2-PINH1.1, U2.9 (IO1), U3.1 (32KHZ)
DP: J2.A6
EOD_RST: J1.10
EPD_3V3: C7.1, EPD_C5.2, J1.15, J1.16, L1.2, Q2.2 (S), TP17.TP
EPD_3V3_C: Q2.1 (G), R_CL1.1, TP13.TP, U2.18 (IO20)
EPD_BUSY: J1.9, TP9.TP, U2.26 (IO3)
EPD_CS: D6.2, J1.12, R9.1, TP10.TP, U2.11 (IO10)
EPD_DC: J1.11, TP11.TP, U2.5 (IO5)
EPD_RST: TP12.TP, U2.21 (IO23)
FLASH_CS: D9.2, R5.1, U1.1 (!CS), U2.12 (IO11)
GDR: J1.2, Q3.1 (G), R4.2
GND: BOOT_BUTTON.2, C1.2, C1_BAT.2, C1_BAT1.2, C1_BAT2.2, C2.2, C2_BAT.2, C3.-, C4_USB.2, C5.2, C5_USB.2, C6.2, C7.2, C8.2, C9.2, C10.2, C10_SUPERCAP.1, CHANGE_BUTTON.2, C_DELAY.2, D1.2 (GND), D3.1 (K), D6.1, D8.1, D9.1, D10.1, D11.1, D12.1, EPC_C6.1, EPC_C8.1, EPD_C1.2, EPD_C2.2, EPD_C5.1, EPD_C7.1, EPD_C9.1, EPD_C10.1, EPD_C11.1, EPD_C12.1, IC1.3 (GND), IC4.2 (VSS), J1.8, J1.17, J1.MP1, J1.MP2, J2.A1, J2.A12, J2.B1, J2.B12, J2.MP1, J2.MP2, J2.MP3, J2.MP4, J3.1, J4.G1 (GND_1), J4.G2 (GND_2), J4.G3 (GND_3), J4.G4 (GND_4), J4.P6 (VSS), MCP73831.2 (VSS), R1_PWRUSB.1, R2.1, R2-USB.2, R2-USB1.1, R2_BAT.1, R4.1, RESET_BUTTON.1, RESET_BUTTON.2, SENSOR2.1 (GND), SENSOR2.5 (SDO), SENSOR2.7 (GND), SJ1.1, TP4.TP, TP5.TP, U1.4 (GND), U2.1 (GND), U2.28 (GND), U2.29_1 (GND), U2.29_2 (GND), U2.29_3 (GND), U2.29_4 (GND), U2.29_5 (GND), U2.29_6 (GND), U2.29_7 (GND), U2.29_8 (GND), U2.29_9 (GND), U3.13 (GND), U4.1 (CTG), U4.4 (GND), U4.6 (QSTRT), U4.9 (EP)
I2C_PW: C1.1, C2.1, R1_PINH.2, R2-PINH.2, SENSOR2.2 (CSB), SENSOR2.6 (VDDIO), SENSOR2.8 (VDD), U2.17 (IO19)
INT_RTC: R1_PINH1.1, TP15.TP, U2.8 (IO0), U3.3 (SQW/!INT)
IO/BOOT: BOOT_BUTTON.3, BOOT_BUTTON.4, C6.1, R_BOOT.1, U2.15 (IO9)
IO/CHANGE: C10.1, CHANGE_BUTTON.3, CHANGE_BUTTON.4, R_CHANGE.1, U2.23 (IO15)
MISO: D12.2, J4.P7 (DAT0), R8.1, TP6.TP, U1.2 (DO(IO1)), U2.27 (IO2)
MOSI: D11.2, J1.14, R7.1, TP7.TP, U1.5 (DI(IO0)), U2.7 (IO7)
unnamed: J2.A5, R2-USB1.2
unnamed: J2.B5, R2-USB.1
unnamed: C1_BAT1.1, D2.1 (CATHODE), IC4.1 (VIN), IC4.3 (CE), Q1.2 (S)
unnamed: C4.1, D3.2 (A), D4.1 (K)
unnamed: GHC_LED.C, R1_BAT.1
unnamed: MCP73831.1 (STAT), R1_BAT.2
unnamed: EPD_C12.2, J1.24
unnamed: MCP73831.5 (PROG), R2_BAT.2
unnamed: EPD_C11.2, J1.23
unnamed: EPD_C10.2, J1.22
unnamed: EPD_C9.2, J1.21
unnamed: EPC_C8.2, J1.20
unnamed: EPD_C7.2, J1.19
unnamed: EPC_C6.2, J1.18
unnamed: EPD_C2.1, J1.5
unnamed: EPD_C1.1, J1.4
unnamed: R1.1, U2.10 (IO8)
unnamed: D7.1 (CATHODE), R_CAPACITOR.1
unnamed: C_DELAY.1, IC1.5 (CT)
PREVGH: D5.1 (K)
PREVGL: D4.2 (A)
RESE: J1.3, Q3.2 (S), R3.2
RESE': R2.2, R3.1, SJ1.2
RESET: C5.1, IC1.1 (VOUT), RESET_BUTTON.3, RESET_BUTTON.4, R_RESET.1, U2.3 (EN)
RTC_RST: U2.16 (IO18), U3.4 (!RST)
RX: TP2.TP, U2.24 (RXD0/GPIO17)
SCK: D10.2, J1.13, J4.P5 (CLK), R6.1, TP8.TP, U1.6 (CLK), U2.6 (IO6)
SCL: J3.4, R2-PINH.1, SENSOR2.4 (SCK), U2.20 (IO22), U3.16 (SCL), U4.7 (SCL)
SDA: J3.3, R1_PINH.1, SENSOR2.3 (SDI), U2.19 (IO21), U3.15 (SDA), U4.8 (SDA)
SRC: C4.2, D5.2 (A), L1.1, Q3.3 (D)
SS_SD: D8.2, J4.P2 (CD/DAT3), R10.1, U2.4 (IO4)
TX: TP1.TP, U2.25 (TXD0/GPIO16)
USB_D+: U2.14 (IO13)
USB_D-: D1.3 (I/O2_1), U2.13 (IO12)
VBAT: C2_BAT.1, MCP73831.3 (VBAT), Q1.3 (D), TP3.TP, U4.2 (CELL), U4.3 (VDD)
VBUS: C1_BAT.1, C4_USB.1, C5_USB.1, D2.2 (ANODE), GHC_LED.A, MCP73831.4 (VIN), PFMF.050.1.2, Q1.1 (G), R1_PWRUSB.2, TP14.TP
VRTC: C8.1, C10_SUPERCAP.2, R_CAPACITOR.2, U3.14 (VBAT)
VUSB: J2.A4, PFMF.050.1.1

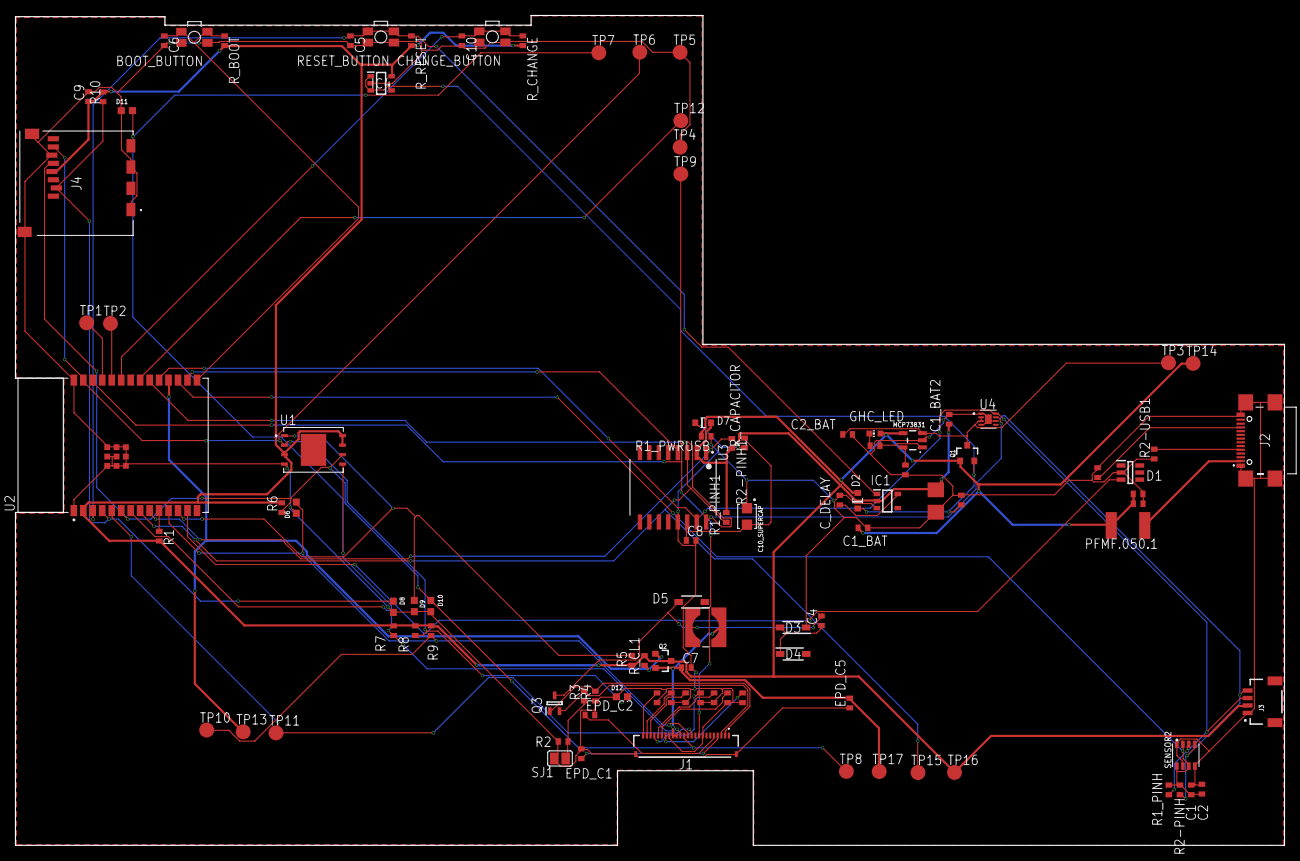
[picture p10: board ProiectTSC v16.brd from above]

Board: 2 copper layers, 170.2 x 111.3 mm, 103 parts (0 on the bottom side), 52 nets.

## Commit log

2025-04-06 Update and rename PnP_ProiectTSC v16_front.csv to Bill of Materials.csv
    [Bill of Materials.csv]
2025-04-06 Update and rename ProiectTSC v16.csv to Pick and Place.csv
    [Pick and Place.csv]

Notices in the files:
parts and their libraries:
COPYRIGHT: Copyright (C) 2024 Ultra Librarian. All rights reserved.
